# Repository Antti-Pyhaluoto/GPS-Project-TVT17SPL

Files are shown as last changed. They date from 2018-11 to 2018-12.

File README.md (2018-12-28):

# GPS Project 

Project for school application project.

Objective: Create a prototype of devices that sends data to database and can be controlled remotely from a web site. Create a website where data is visualized and deveice can be controlled.

Goal: GPS tracker that sends location data to database and a website that draws location data from database to map.

Additional goals: Drawing speed and distance traveled graphs from data and displaying live location data on website.

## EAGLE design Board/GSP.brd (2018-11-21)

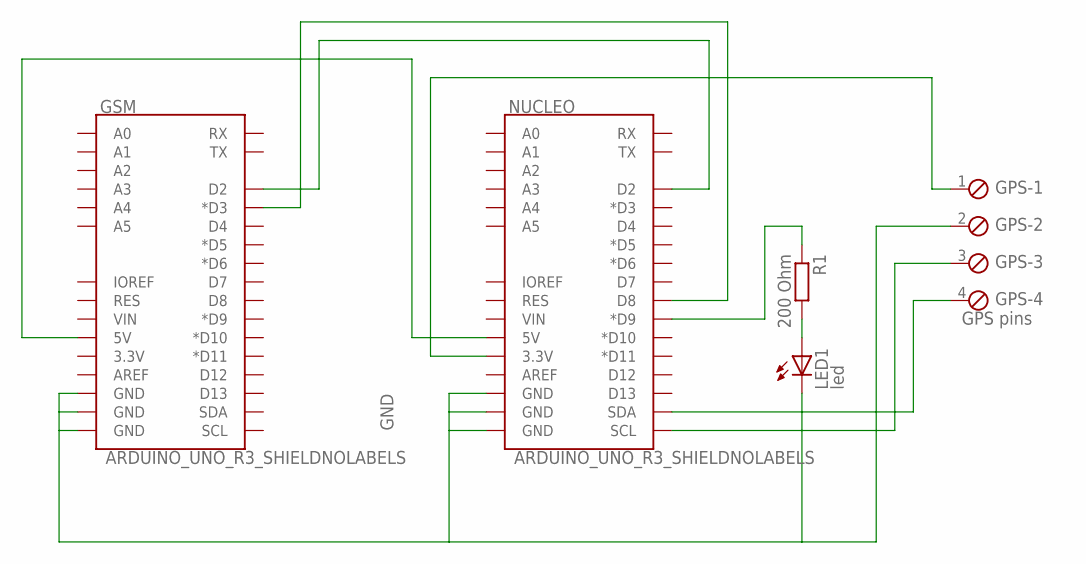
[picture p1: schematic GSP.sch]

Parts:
GPS: GPS pins; 4POL254
GSM: ARDUINO_UNO_R3_SHIELDNOLABELS; UNO_R3_SHIELD_NOLABELS
LED1: led; LED3MM
NUCLEO: ARDUINO_UNO_R3_SHIELDNOLABELS; UNO_R3_SHIELD_NOLABELS
R1: 200 Ohm; 0204/5

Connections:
GND: GPS.2, GSM.GND@0 (GND), GSM.GND@1 (GND), GSM.GND@2 (GND), LED1.K (C), NUCLEO.GND@0 (GND), NUCLEO.GND@1 (GND), NUCLEO.GND@2 (GND)
unnamed: GSM.5V, NUCLEO.5V
unnamed: NUCLEO.D9 (*D9), R1.1
unnamed: LED1.A, R1.2
unnamed: GPS.1, NUCLEO.3.3V
unnamed: GSM.D2, NUCLEO.D2
unnamed: GSM.D3 (*D3), NUCLEO.D8
unnamed: GPS.4, NUCLEO.SDA
unnamed: GPS.3, NUCLEO.SCL

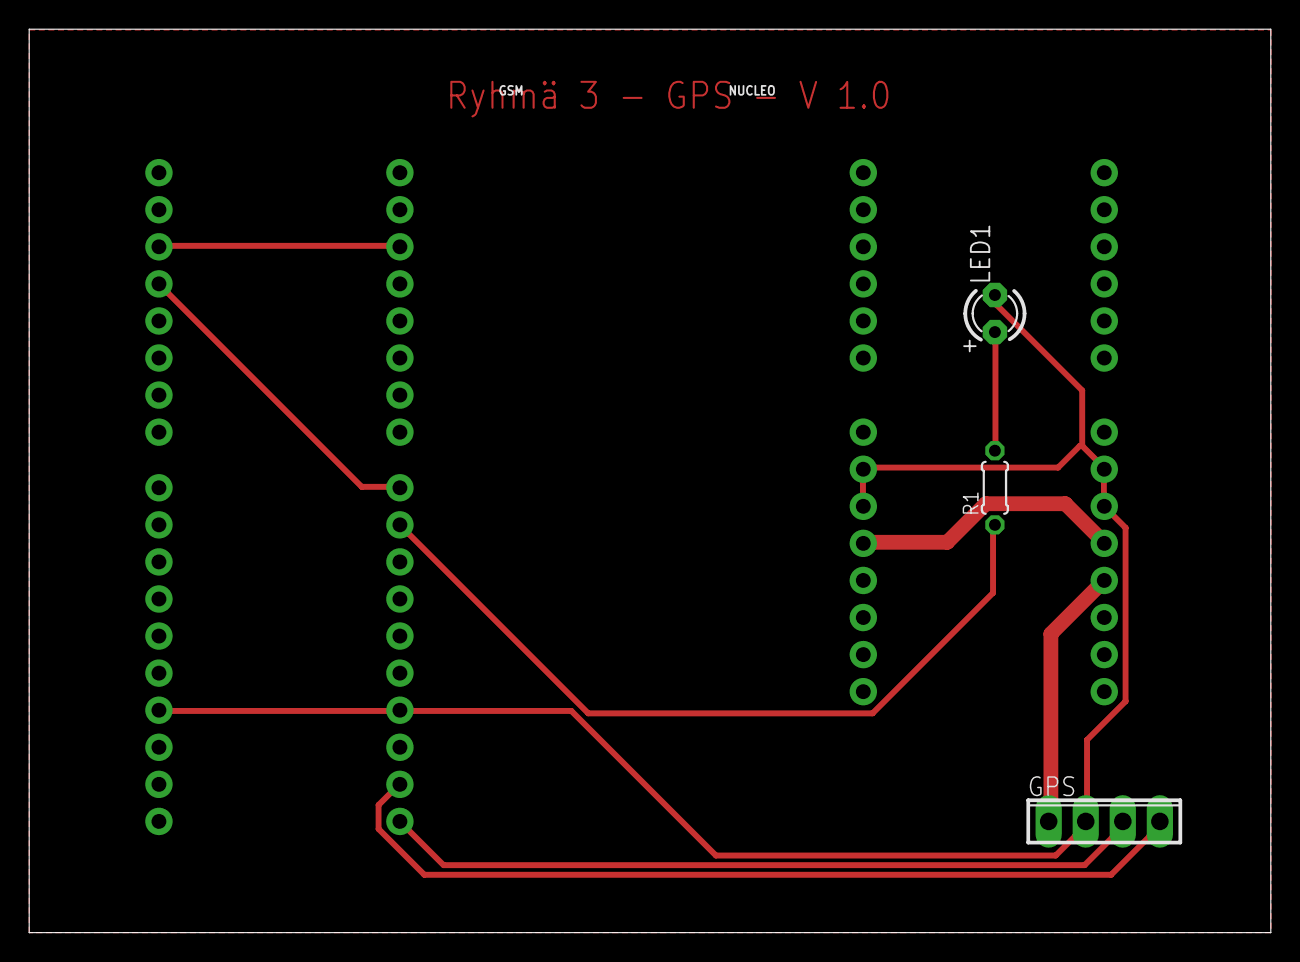
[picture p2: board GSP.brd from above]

Board: 2 copper layers, 85.1 x 61.9 mm, 5 parts (0 on the bottom side), 9 nets.

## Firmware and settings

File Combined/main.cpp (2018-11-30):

#include "mbed.h"
#include "rtos.h"
#include <string.h>

Serial gsm(D8, D2);
Serial gps(D14, D15);
Serial pc(USBTX, USBRX);
DigitalOut led(LED2);
//Thread gpsthread;
//Thread gsmthread;
DigitalIn button(USER_BUTTON);

Timer ajastin;
Timer taajuusAja;

//Alku käskyt

char *alku[][2][50] = {
	{{"AT"},			{"OK"}},		//Varmistetaan että modeemi on päällä
//	{{"AT+CMEE=2"},		{"OK"}},		//Virhee kirjallisiksi
	{{"AT+CPIN=0000"},	{"Call Ready"}},//Annetaan PIN koodi
	{{"AT+CGREG?"},		{"+CGREG: 0,1"}},//Varmistetaan että on rekisteröitynyt koti verkkoon.
	{{"AT+CGACT=1,1"},	{"OK"}},		//Aktivoidaan PDP konteksti
	{{"AT+QIREGAPP"},	{"OK"}},		//Käynnistetään TCP/IP protocolla
	{{"AT+QIACT"},		{"OK"}},		//Aktivoidaan TCP/IP
	{{"AT+QILOCIP"},	{"."}}			//Luetaan oma IP
};

char *lahetys[][2][50] = {
	{{"AT+QIOPEN=\"TCP\",\"193.167.100.74\",80"}, {"CONNECT OK"}}, //Koulun IP
	{{"AT+QISEND"}, {">"}}
};

//Globaaleja muuttujia tiedon siirtämiseksi GPS:ltä GSM:lle.
double Lat = 0.0, Lon = 0.0, oikeaHDOP = 0.0;
float kesto = 0, odotus = 0;
int Aika = 0, ID = 0, taajuus = 3; //Aika muodossa hhmmss, taajuus kuinka monen sekunnin välein pitäisi lähettää paikkatieto.
char viesti[1000];
char gsmBuffer[300];

void GPS_func();
void ledi();
void lahetaLueLoop(bool alku);
void lue(int aika);
void laheta(char *kasky);
void lahetaJaLue(char *kasky, int aika);
int lahetaJaOdota(char *kasky, char *vastaus, int aika);
int lahetaJaOdota(char *kasky, char *vastaus, char *toinen, int aika);
int lueBufferiin(char *buffer, char *vastaus, int aika);
void yhdistaTCP(int miinus);


int main(){
	pc.baud(115200);
	gsm.baud(115200);
	pc.printf("Aloitus. GSM GPS yhdistelmä.\n");
	lahetaLueLoop(true);
	
	pc.printf("GSM yhdistäminen.\n");
	int kumpi = lahetaJaOdota("AT+CPIN?", "READY", "SIM PIN", 3);
	//pc.printf("Kumpi:%d", kumpi);
	if(kumpi != 0){
		int l = sizeof(alku)/sizeof(alku[0]);
		//Käydään läpi alku komentosarja
		for(int i = 0; i < l; i++){
			int j = lahetaJaOdota(alku[i][0][0], alku[i][1][0], 10);
			wait(0.5);
			if(j != 0 ){
				pc.printf("Fail %d:", i);
				pc.printf(alku[i][0][0]);
				pc.printf("\n");
				i--;
				wait(1);
			}
		}
	}
	pc.printf("GSM valmis.");
	wait(1);
	//Kysytään uusi ID.
	yhdistaTCP(0);
	
	lahetaJaOdota("GET /~t6heja02/lisaa.php HTTP/1.1\r\nHost: www.students.oamk.fi\r\nConnection: close\r\n\r\n\032", "SEND OK", 10);
	
	lueBufferiin(&gsmBuffer[0], "CLOSED", 3);
	
	//pc.printf("---------------------Luettu.");
	//pc.printf(gsmBuffer);
	char *gsmToken;
	strtok(gsmBuffer, "$");
	gsmToken = strtok(NULL, "\n");
	ID = atoi(gsmToken) + 1;
	pc.printf("\nUusi ID:%d\nOdotetaan GPS.", ID);
	
	//Odotetaan GPS.
	while(true){
		GPS_func();
		if(Lat != 0 && Lon != 0){
			break;
		}
	}
	
	pc.printf("GPS löyty. Odotetaan 5 sec.\n");
	wait(5);
	
	while(true){
		pc.printf("\nAlku\n");
		taajuusAja.start();
		ledi();
		GPS_func();
		pc.printf("OK Aika:%d\tLat:%f\tLon:%f\tHDOP:%f\n", Aika, Lat, Lon, oikeaHDOP);
		if(floor(Lon) == 0.0 || floor(Lat) == 0.0){
			printf("Virheellistä dataa/Heikko signaali");
		}
		else{
			yhdistaTCP(0);//qiopen ja qisend
			sprintf(viesti, "GET /~t6heja02/lisaa.php?ID=%d&Aika=%d&Lat=%f&Lon=%f&HDOP=%f HTTP/1.1\r\nHost: www.students.oamk.fi\r\nConnection: close\r\n\r\n\032", ID, Aika, Lat, Lon, oikeaHDOP);
			//lahetaJaOdota("AT+QISEND", ">", 5);
			lahetaJaOdota(viesti, "SEND OK", 5);
			
			
			lueBufferiin(&gsmBuffer[0], "CLOSED", 3);
			
			strtok(gsmBuffer, "$");
			gsmToken = strtok(NULL, "\n");
			taajuus = atoi(gsmToken);
			
			
			//lahetaJaOdota("", "CLOSED", 10);
		}
		ledi();
		kesto = taajuusAja.read();
		taajuusAja.stop();
		taajuusAja.reset();
		odotus = taajuus - kesto;
		if(odotus <= 0)odotus = 0;
		pc.printf("\nOdotus %f sec.\n", odotus);
		wait(odotus);
	}
	
}

void GPS_func(){
		char buffer[460];
		for(int i = 0; i< 450; i++)
		{
		
			char c = gps.getc();
			
			buffer[i] = c;
		
		
		}
		
		//pc.puts(buffer);		//tulostaa bufferin raakadataa
	
		//Haluttu input = "$GPGGA,xxxxx.xx,xxxx.xxxxxx,x,xxxxxx.xxxxx,x,x,xx,x.xx,xx.x,x,xx.x,x,,*xx";
		
		char *token;		
		token = strtok(buffer, "$");
		
		//pc.printf("TYHJÄ = %s\n", token);
			
		char* paikannusTieto = {"GPGGA"};
	
		while (true){
			
			bool loyty = false;
			
			token = strtok(NULL, "$");
			
			for(int i = 0; i < 5; i++)
			{
				if (paikannusTieto[i] != token[i])
				{
					//pc.printf("Väärä merkki!\n");
					loyty = true;
					break;
				}
			}
			if (!loyty){
				
			break;				//Takaisin loopin alkuun etsimään "GPGGA"
			}

		}
		while (gps.readable())
		{
			char c = gps.getc();
		}
		token = strtok(token, ",.");
		//pc.printf(" = %s\n", token);
			
		token = strtok(NULL, ",.");
		//pc.printf("token = %s\n", token);
		int fix = atoi(token);
		int UTC = fix + 20000;
		
		token = strtok(NULL, ",.");
		//pc.printf("token = %s\n", token);
		int nolla = atoi(token);
		
		token = strtok(NULL, ",.");
		//pc.printf("token = %s\n", token);
		int kulma = (atoi(token));					//JAA 100
		double todellinenKulma = floor(kulma/100);	// 65 !!
		
		token = strtok(NULL, ",.");
		//pc.printf("token = %s\n", token);
		double minuutit = atoi(token);
		double todellisetMinuutit = minuutit/100000;	//0.0232000
		
		todellisetMinuutit = (kulma - todellinenKulma * 100)+todellisetMinuutit;
		
		double latitude = todellinenKulma + (todellisetMinuutit / 60);
		
		token = strtok(NULL, ",.");
		//pc.printf("token = %s\n", token);
		int Korkeus = atoi(token);
		
		token = strtok(NULL, ",.");
		//pc.printf("token = %s\n", token);
		double a6 = atoi(token);						//2530.000000				
		double LeveysKulma = a6/100;
		LeveysKulma = floor(LeveysKulma);			//Pyöristää kahden desimaalin kokonaisluvuksi (floor=alaspäin pyöristys)
		
		double valivaihe = a6 - (LeveysKulma * 100);	// = 30 MINUUTIT
		
		
		token = strtok(NULL, ",.");
		//pc.printf("token = %s\n", token);
		double a7 = atoi(token);
		double leveydenAika= a7/100000;				// 0,55534
		
		double longitude = LeveysKulma + (valivaihe + leveydenAika) / 60;
		
		token = strtok(NULL, ",.");
		//pc.printf("token = %s\n", token);			//EAST
	//	int leveysSuunta = atoi(token);
		
		token = strtok(NULL, ",.");
	//	pc.printf("token = %s\n", token);
	//	int a9 = atoi(token);						//fix quality
		
		token = strtok(NULL, ",.");
	//	pc.printf("token = %s\n", token);
	//	int a10 = atoi(token);						//number of satellites
		
		token = strtok(NULL, ",.");
	//	pc.printf("token = %s\n", token);
		double HDOP = atoi(token);					//HDOP
		
		token = strtok(NULL, ",.");
	//	pc.printf("token = %s\n", token);			//Altitude from sea level
	//	int a12 = atoi(token);
		
		//pc.printf("\naika = %d\n longitude = %f\n Latitude = %f HDOP= %f\n\n\n\n",UTC, longitude, latitude, HDOP);
		
		Lat = latitude;
		Aika = UTC;
		Lon = longitude;
		oikeaHDOP = HDOP;
}

void ledi(){
	led = !led;
}

//Kaikki mitä pc:lle kirjoitetaan lähetetään GSM:lle ja päinvastoin.
void lahetaLueLoop(bool alku){
	while(true){
		if(pc.readable()){
			while(pc.readable()){
				gsm.putc(pc.getc());
			}
		}
		if(gsm.readable()){
			while(gsm.readable()){
				pc.putc(gsm.getc());
			}
		}
		if(alku && !button){//Poistutaan loopista napin painalluksella jos alku == true.
			wait(0.5);
			if(button)break;
		}
	}
}

//Vaihto ehto wait fuktiolle mikä kuitenkin lukee tuloksia gsm:ltä.
void lue(int aika){
	pc.printf("------------------------------------------------------");
	ajastin.start();
	while(true){
		if(gsm.readable()){
			char c = gsm.getc();
			pc.putc(c);
		}
		if(aika <= ajastin.read()){
			ajastin.stop();
			ajastin.reset();
			break;
		}
	}
}

//Lähettää käskyn gsm:lle.
void laheta(char *kasky){
	gsm.printf(kasky);
	gsm.puts("\r");
	//pc.printf(kasky);
	//pc.puts("\n");
}

//Lähettää käskyn gsm:lle ja lukee vastauksia tietyn aikaa.
void lahetaJaLue(char *kasky, int aika){
	laheta(kasky);
	ajastin.start();
	while(true){
		if(gsm.readable()){
			char c = gsm.getc();
			pc.putc(c);
			//if(c == "\r")break;
		}
		if(aika < ajastin.read()){
			wait(0.1);
			ajastin.stop();
			ajastin.reset();
			break;
		}
	}
}

//Lähettää käskyn gsm:lle ja odottaa tiettyä vastausta.
//Jos vastaus saadaan palauttaa 0, jos ei saada tietyssä ajassa palauttaa 1.
int lahetaJaOdota(char *kasky, char *vastaus, int aika){
	laheta(kasky);
	int indeksi = 0, pituus = strlen(vastaus);
	ajastin.start();
	
	while(true){
		if(gsm.readable()){
			char c = gsm.getc();
			//pc.putc(c);
			if(c == vastaus[indeksi]){
				indeksi++;
			}
			else{
				indeksi = 0;
			}
			if(pituus == indeksi){
				ajastin.stop();
				ajastin.reset();
				return 0;
			}
			
		}
		if(aika < ajastin.read()){
			wait(0.1);
			ajastin.stop();
			ajastin.reset();
			return -1;
		}
	}
}

int lahetaJaOdota(char *kasky, char *vastaus, char *toinen, int aika){
	laheta(kasky);
	int indeksi = 0, pituus = strlen(vastaus);
	int indeksi2 = 0, pituus2 = strlen(toinen);
	ajastin.start();
	
	while(true){
		if(gsm.readable()){
			char c = gsm.getc();
			//pc.putc(c);
			if(c == vastaus[indeksi]){
				indeksi++;
			}
			else{
				indeksi = 0;
			}
			
			if(c == toinen[indeksi2]){
				indeksi2++;
			}
			else{
				indeksi2 = 0;
			}
			
			if(pituus == indeksi){
				wait(0.1);
				ajastin.stop();
				ajastin.reset();
				return 0;
			}
			if(pituus2 == indeksi2){
				wait(0.1);
				ajastin.stop();
				ajastin.reset();
				return 1;
			}
			
		}
		if(aika < ajastin.read()){
			wait(0.1);
			ajastin.stop();
			ajastin.reset();
			return -1;
		}
	}
}

//Lähettää käskyn gsm:lle, odottaa tiettyä vastausta ja kirjoittaa kaiken lukemansa bufferiin.
int lueBufferiin(/*char *kasky, */char *buffer, char *vastaus, int aika){
	//laheta(kasky);
	int indeksi = 0, pituus = strlen(vastaus);
	ajastin.start();
	int j = 0;
	while(true){
		if(gsm.readable()){
			char c = gsm.getc();
			//pc.putc(c);
			buffer[j] = c;
			j++;
			if(c == vastaus[indeksi]){
				indeksi++;
			}
			else{
				indeksi = 0;
			}
			if(pituus == indeksi){
				return 0;
			}
			
		}
		if(aika < ajastin.read()){
			wait(0.1);
			ajastin.stop();
			ajastin.reset();
			return -1;
		}
	}
}

void yhdistaTCP(int miinus){
	int l = sizeof(lahetys)/sizeof(lahetys[0]);
	for(int i = 0; i < l - miinus; i++){
		int j = lahetaJaOdota(lahetys[i][0][0], lahetys[i][1][0], "ALREADY CONNECT", 5);
		wait(0.1);
		if(j == -1){
			//pc.printf("Väärä vastaus.TCP");
			wait(1);
			i--;
		}
	}
}

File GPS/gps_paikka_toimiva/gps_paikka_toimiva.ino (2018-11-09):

/*
 * Rui Santos 
 * Complete Project Details http://randomnerdtutorials.com
 */
 
#include <TinyGPS++.h>
#include <SoftwareSerial.h>

static const int RXPin = 4, TXPin = 3;
static const uint32_t GPSBaud = 9600;

// The TinyGPS++ object
TinyGPSPlus gps;

// The serial connection to the GPS device
SoftwareSerial ss(RXPin, TXPin);

void setup(){
  Serial.begin(9600);
  ss.begin(GPSBaud);
}

void loop(){
  // This sketch displays information every time a new sentence is correctly encoded.
  while (ss.available() > 0){
    gps.encode(ss.read());
    if (gps.location.isUpdated()){
      Serial.print("Latitude= "); 
      Serial.print(gps.location.lat(), 6);
      Serial.print(" Longitude= "); 
      Serial.print(gps.location.lng(), 6);
      Serial.print(" Speed= ");
      Serial.print(gps.speed.mph(), 6);
      Serial.print(" Altitude= ");
      Serial.println(gps.altitude.meters());
    }
  }
  
}

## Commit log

2018-11-09 New main that autmotically issues AT commands needed for GPRS TCP/IP communication.
    [gps_paikka_toimiva.ino]
2018-11-19 Added security/filtering for the input values
2018-11-20 PCB board files added.
    [GSP.brd, GSP.sch]
2018-11-21 Updated board. Test of webpage.
    [GSP.brd, GSP.sch]
2018-11-26 Resolved conflicts for real.
    [main.cpp]
2018-11-27 GPS data filtering improved
2018-11-27 GPS data filtering improved_version2
2018-11-27 Added led to idicate sending of location data.
2018-11-29 Added update frequency functionality. Removed printing of AT commands.

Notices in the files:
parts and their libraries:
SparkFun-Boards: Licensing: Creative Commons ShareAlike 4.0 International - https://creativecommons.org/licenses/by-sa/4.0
